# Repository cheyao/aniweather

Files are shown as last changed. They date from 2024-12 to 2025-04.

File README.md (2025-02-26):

<h1 align="center">Aniweather - Your personal anime weather station!</h1>

This is a 3D weather station! You can choose between displaying daily waifu pics and the current weather.

Made for #asylum. The main API code is at https://github.com/cheyao/short with nest :D

PCB image
3D top view
3D bottom view
Case view

To change the settings, edit `firmware/settings.h`! The weather info is mostly parsed on nest.

[ x ] I ran DRC in KiCad and have made sure there are 0 errors!

### BOM 

Provided by dari // alexren:
- 1x WeMos S2 Mini (as a cheaper replacement for the S2) WITHOUT FEMALE HEADERS
- 1x ST7735 1.8" LCD display WITHOUT FEMALE HEADERS. Male headers soldered!

I will be sourcing the following parts with my grant:
- 1x PCB from JLCPCB
    - $2 for 5x + $1.50 shipping
- LCSC:
    - 3x Ceramic THT 1uF capacitor
    - 6x Ceramic THT 0.1uF capacitor
    - 3x Ceramic SMD 0805 10uF capacitor
    - 1x 10ohm THT Resistor
    - 1x 100ohm THT Resistor
    - 1x 470ohm THT Resistor
    - 6x 10kohm THT Resistor
    - 1x TPS2116DRLR
    - 1x TPS63001DRCR

HOME:
- 1x TP4056
- 1x LIPO
- 1x 3D printed case

TOTAL: 15.99+3.5=19.45$

Green LEDs will be brought with the keyboard (min 100 :heavysob:)

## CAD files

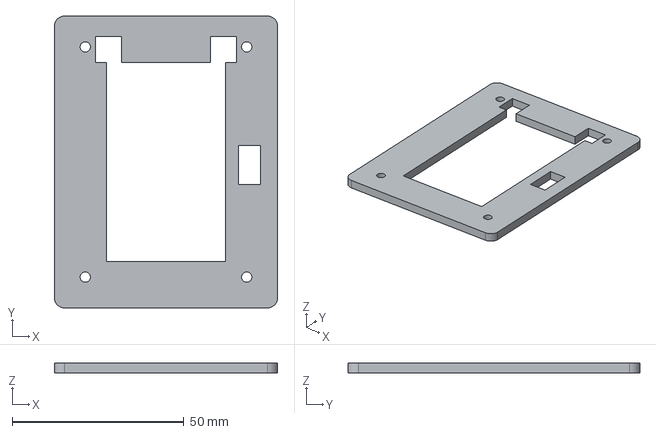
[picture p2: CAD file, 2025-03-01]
CAD/cover.step
65.0 x 85.0 x 3.00 mm

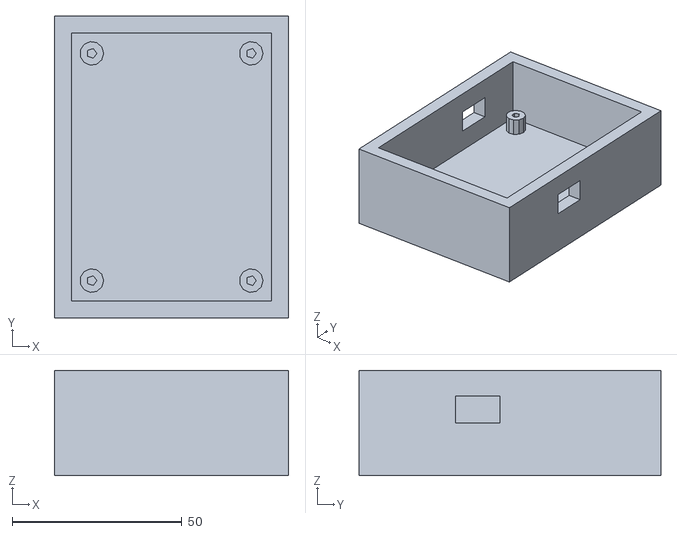
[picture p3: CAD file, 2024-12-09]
CAD/top.stl
69.0 x 89.0 x 31.0

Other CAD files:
CAD/back.scad
CAD/common.scad
CAD/cover.scad
CAD/cover.stl

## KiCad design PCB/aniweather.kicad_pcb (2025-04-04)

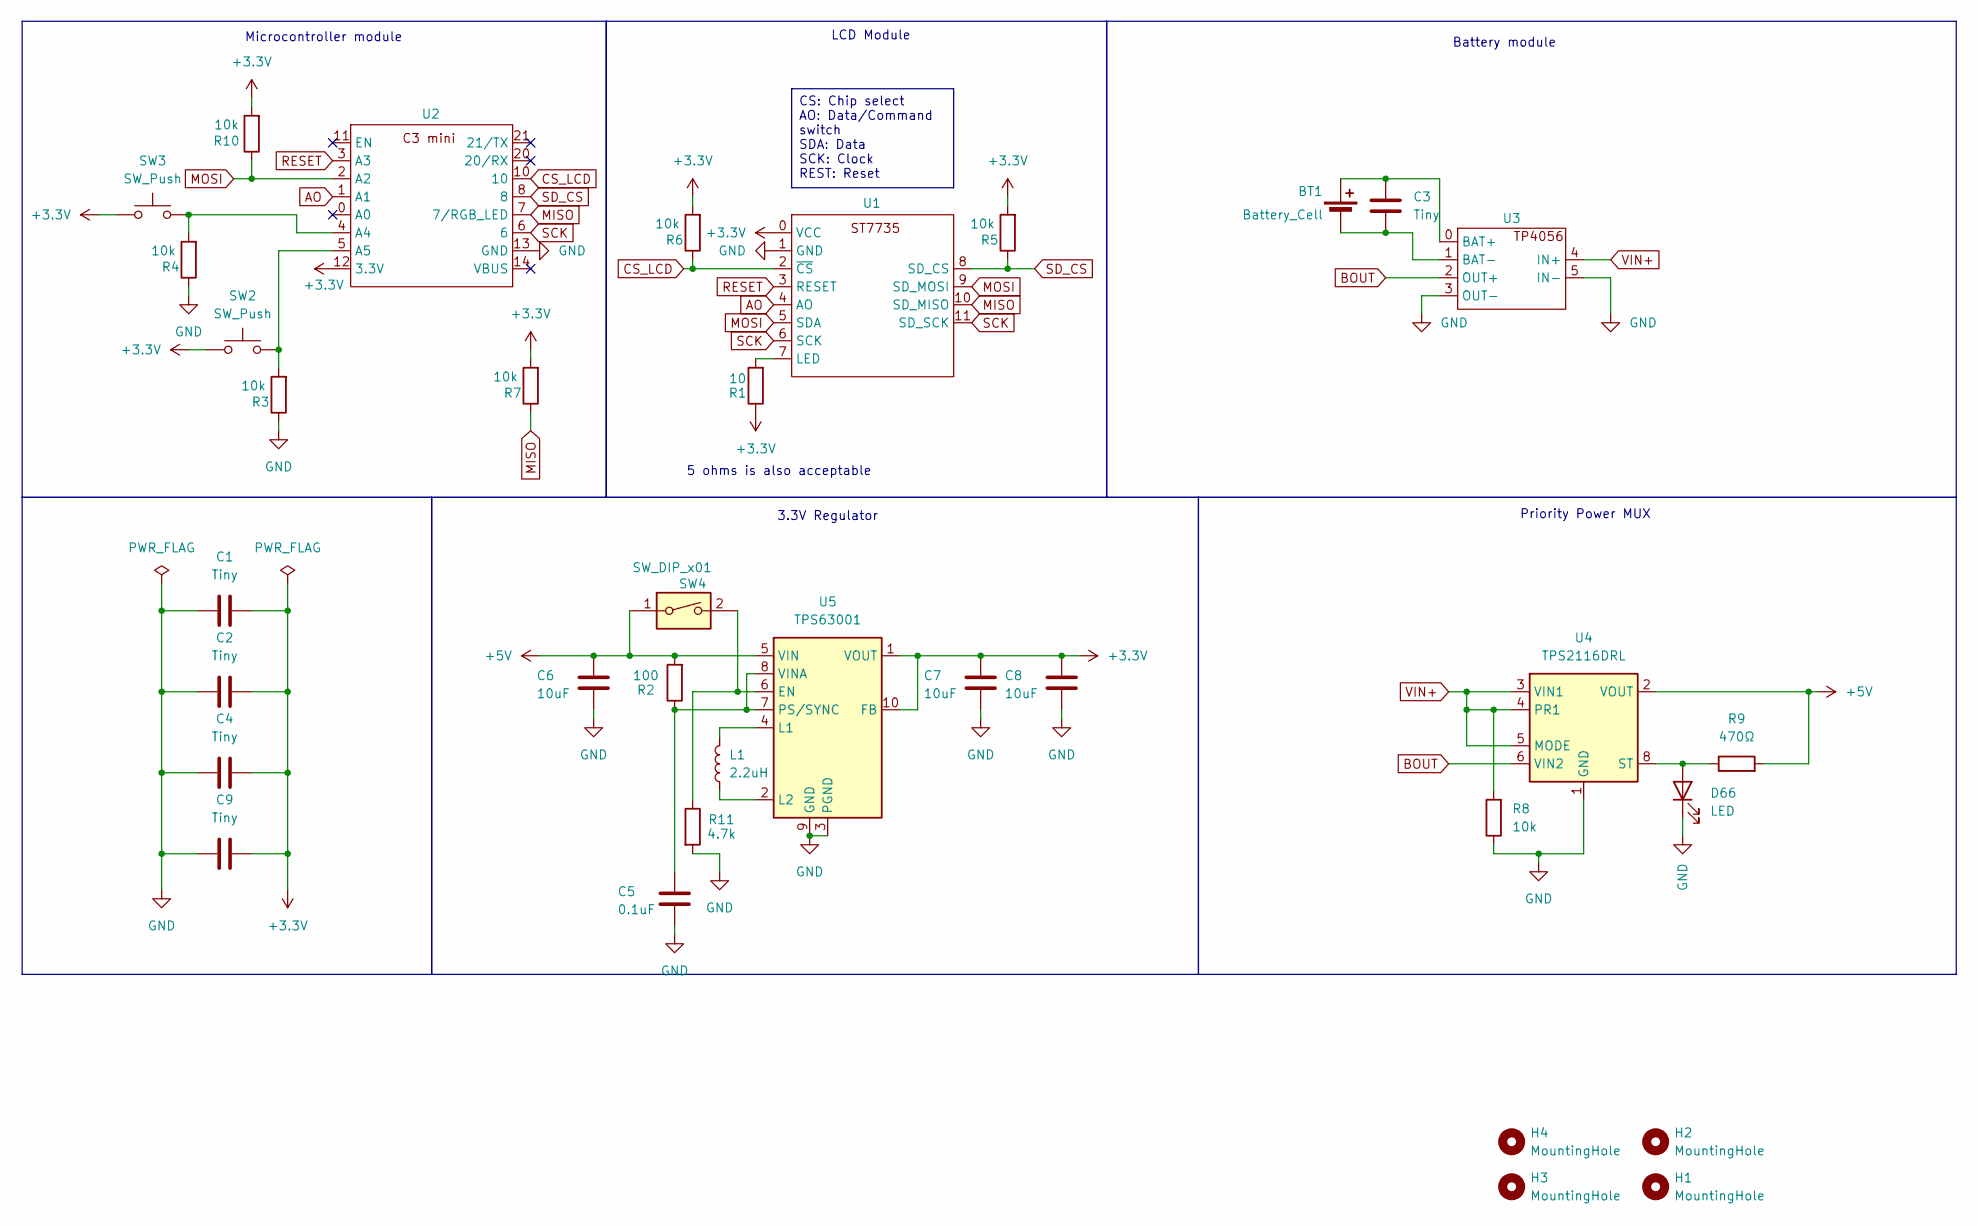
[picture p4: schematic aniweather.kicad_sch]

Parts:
BT1: Battery_Cell; TestPoint_2Pads_Pitch5.08mm_Drill1.3mm
C1, C2, C3, C4, C9: Tiny; C_0805_2012Metric_Pad1.18x1.45mm_HandSolder
C5: 0.1uF; C_0805_2012Metric_Pad1.18x1.45mm_HandSolder
C6, C7, C8: 10uF; C_0805_2012Metric_Pad1.18x1.45mm_HandSolder
D66: LED; LED_0603_1608Metric_Pad1.05x0.95mm_HandSolder
H1, H2, H3, H4: MountingHole; MountingHole_3.2mm_M3
L1: 2.2uH; NR3015T2R2M
R1: 10; R_0805_2012Metric_Pad1.20x1.40mm_HandSolder
R2: 100; R_0805_2012Metric_Pad1.20x1.40mm_HandSolder
R3, R4, R5, R6, R7, R8, R10: 10k; R_0805_2012Metric_Pad1.20x1.40mm_HandSolder
R9: 470Ω; R_0805_2012Metric_Pad1.20x1.40mm_HandSolder
R11: 4.7k; R_0805_2012Metric_Pad1.20x1.40mm_HandSolder
SW2, SW3: SW_Push; SW_PUSH_6mm
SW4: SW_DIP_x01; SW_DIP_SPSTx01_Slide_9.78x4.72mm_W7.62mm_P2.54mm
U1: ST7735
U2: WEMOS_C1_mini
U3: TP4056
U4: TPS2116DRL; SOT-583-8
U5: TPS63001; Texas_DRC0010J_ThermalVias

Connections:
+3.3V: C1.2, C2.2, C4.1, C7.1, C8.1, C9.1, R1.1, R5.2, R6.2, R7.2, R10.2, SW2.1, SW3.1, U1.0 (VCC), U2.12 (3.3V), U5.1 (VOUT), U5.10 (FB)
+5V: C6.1, R2.2, R9.2, SW4.1, U4.2 (VOUT), U4.7 (VOUT), U5.5 (VIN)
AO: U1.4 (AO), U2.1 (A1)
BOUT: U3.2 (OUT+), U4.6 (VIN2)
CS_LCD: R6.1, U1.2 (~CS), U2.10
GND: C1.1, C2.1, C4.2, C5.2, C6.2, C7.2, C8.2, C9.2, D66.1 (K), R3.1, R4.1, R8.1, R11.2, U1.1 (GND), U2.13 (GND), U3.3 (OUT-), U3.5 (IN-), U4.1 (GND), U5.3 (PGND), U5.9 (GND), U5.11 (PGND)
MISO: R7.1, U1.10 (SD_MISO), U2.7 (7/RGB_LED)
MOSI: R10.1, U1.5 (SDA), U1.9 (SD_MOSI), U2.2 (A2)
unnamed: BT1.1 (+), C3.1, U3.0 (BAT+)
unnamed: BT1.2 (-), C3.2, U3.1 (BAT-)
unnamed: D66.2 (A), R9.1, U4.8 (ST)
unnamed: R1.2, U1.7 (LED)
unnamed: R4.2, SW3.2, U2.4 (A4)
unnamed: R3.2, SW2.2, U2.5 (A5)
unnamed: R11.1, SW4.2, U5.6 (EN)
unnamed: L1.2, U5.4 (L1)
unnamed: L1.1, U5.2 (L2)
unnamed: C5.1, R2.1, U5.7 (PS/SYNC), U5.8 (VINA)
RESET: U1.3 (RESET), U2.3 (A3)
SCK: U1.6 (SCK), U1.11 (SD_SCK), U2.6
SD_CS: R5.1, U1.8 (SD_CS), U2.8
VIN+: R8.2, U3.4 (IN+), U4.3 (VIN1), U4.4 (PR1), U4.5 (MODE)

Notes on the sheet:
Microcontroller module
Battery module
3.3V Regulator
Priority Power MUX
5 ohms is also acceptable
LCD Module
CS: Chip select AO: Data/Command switch SDA: Data SCK: Clock REST: Reset

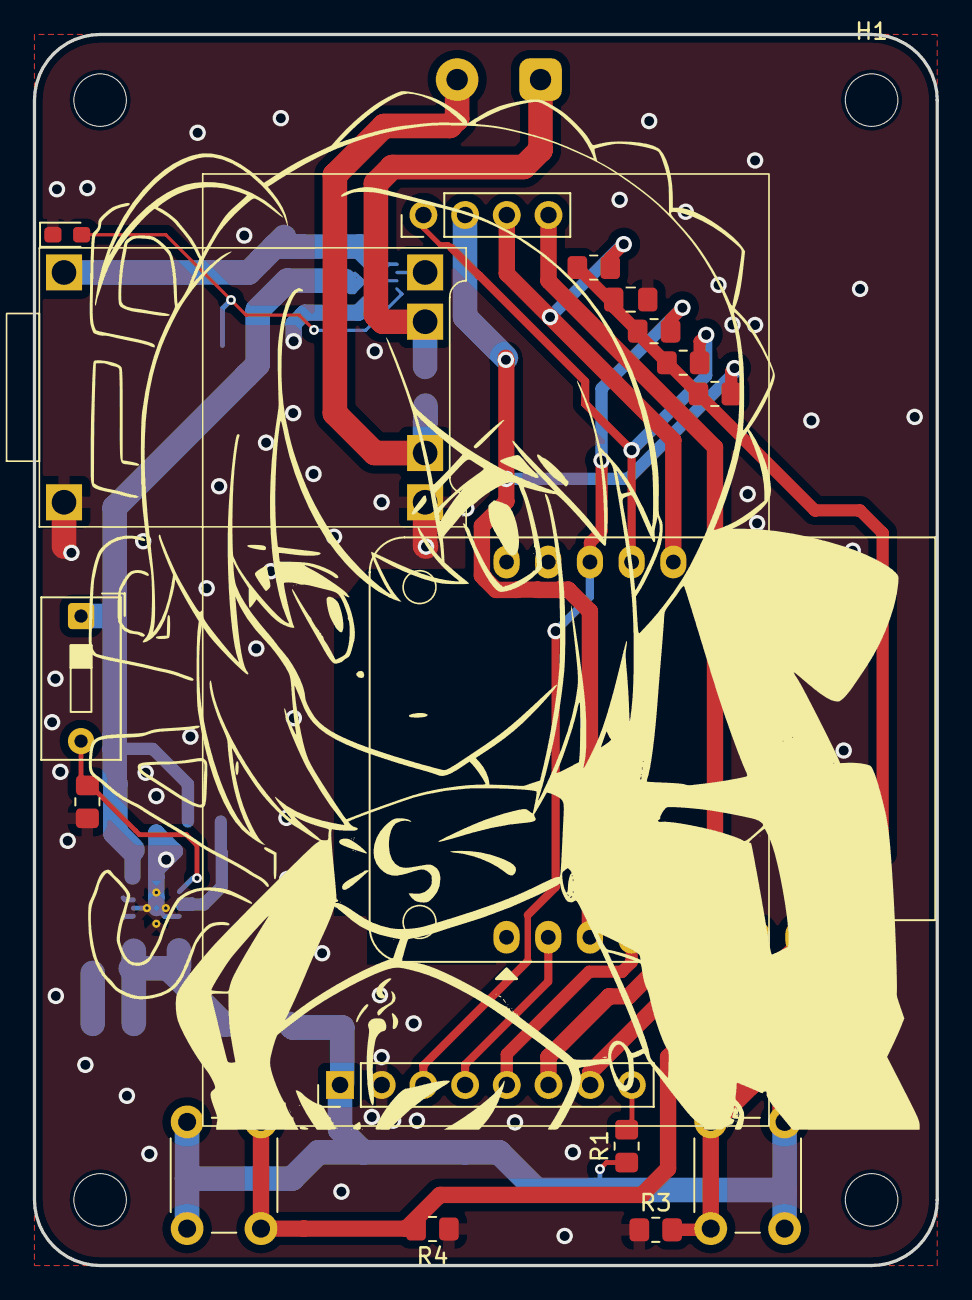
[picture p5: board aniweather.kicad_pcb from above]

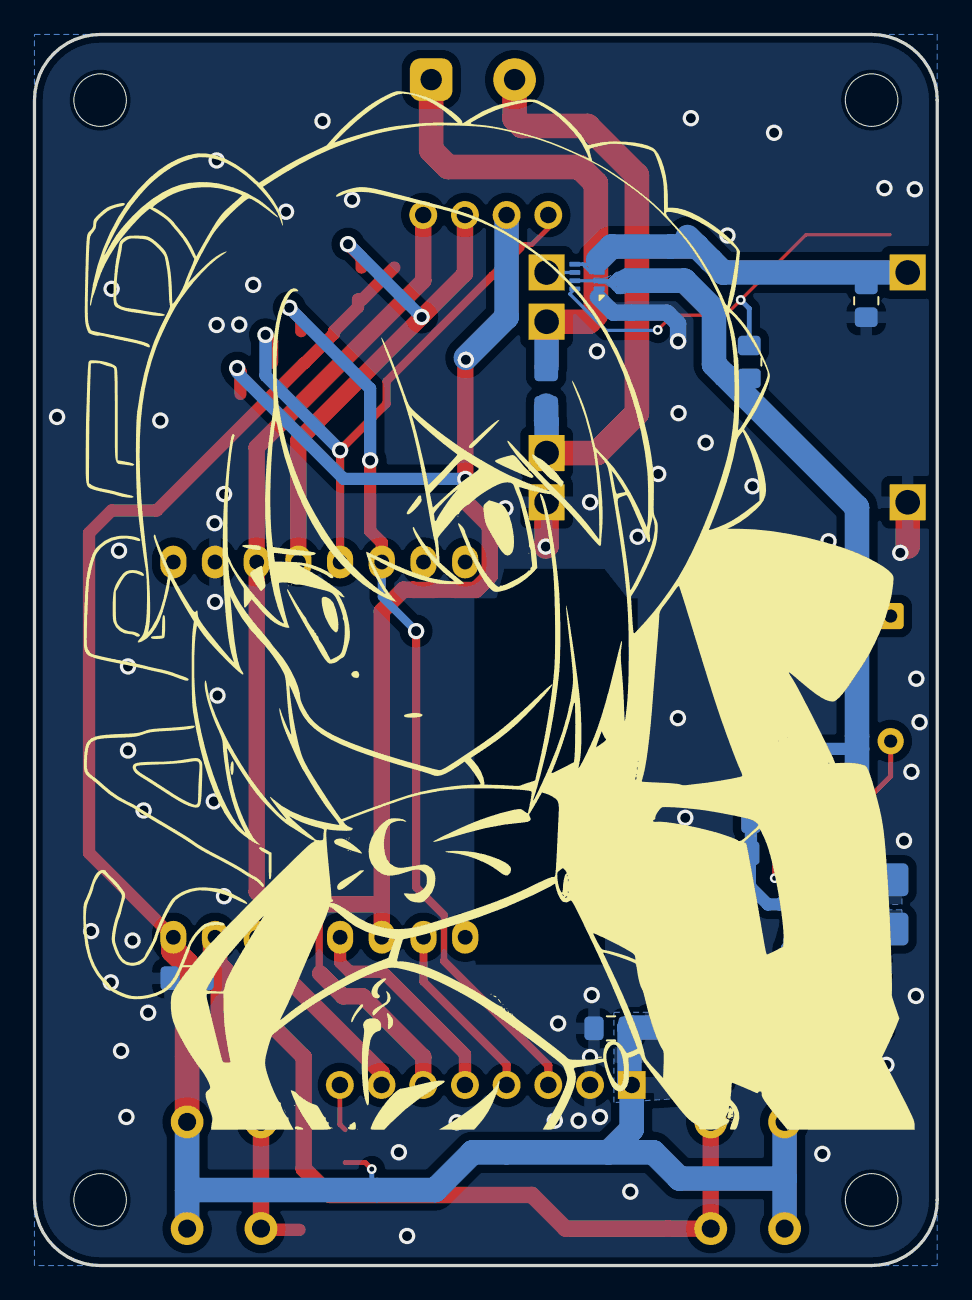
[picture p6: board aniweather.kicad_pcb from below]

Board: 2 copper layers, 55.0 x 75.0 mm, 37 parts (16 on the bottom side), 22 nets.

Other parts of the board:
G1, G2: LOGO

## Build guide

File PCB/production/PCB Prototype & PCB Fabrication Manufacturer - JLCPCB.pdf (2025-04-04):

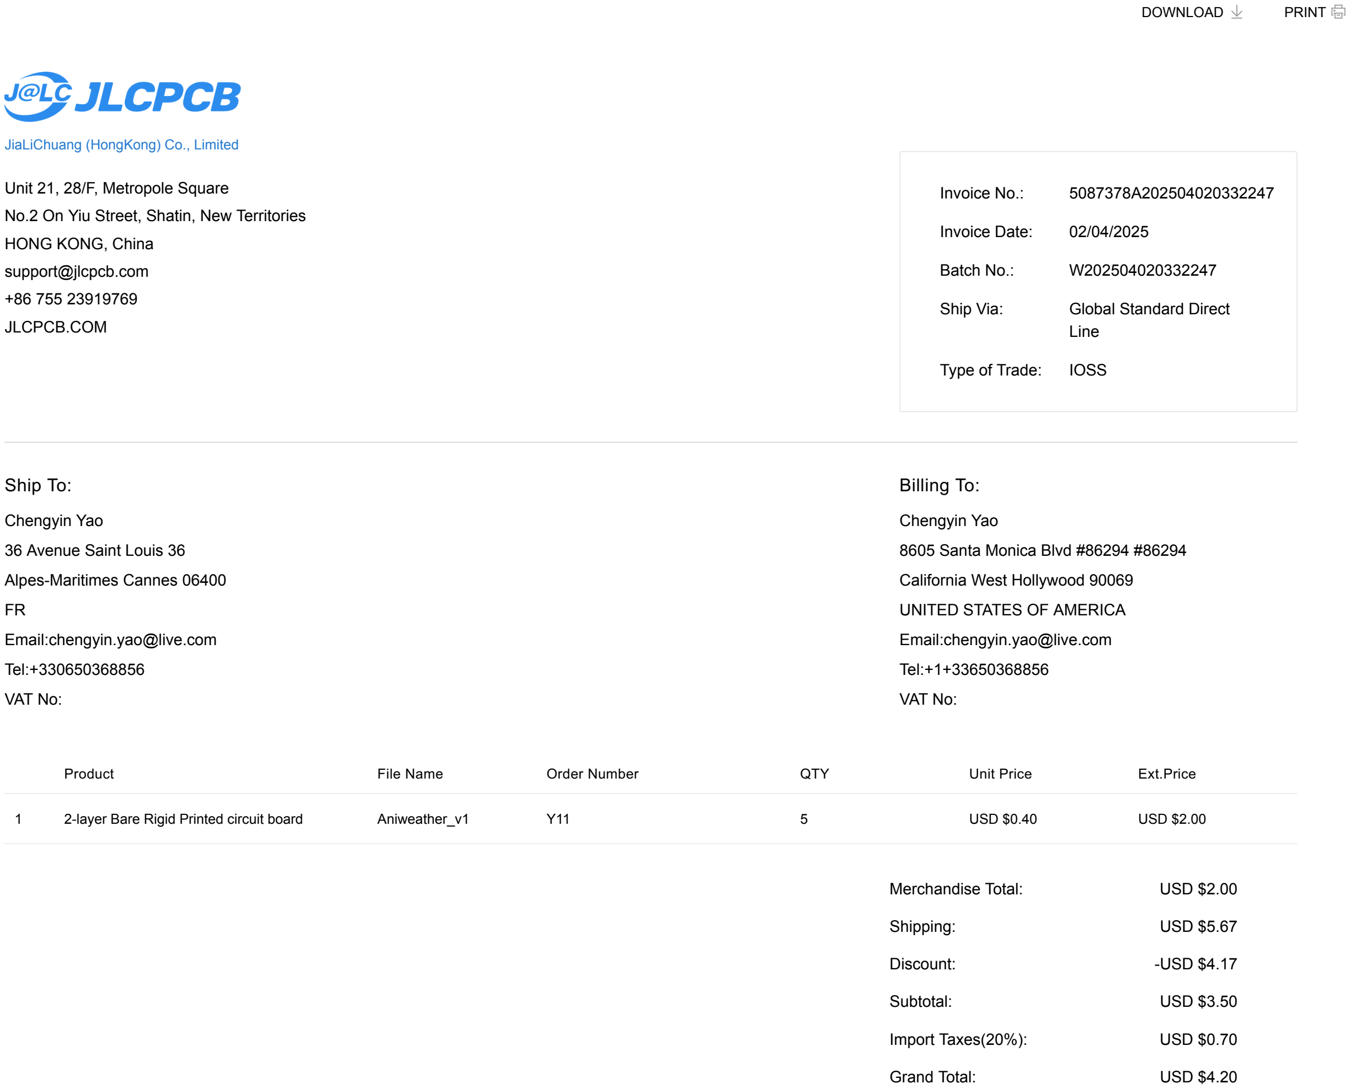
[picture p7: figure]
DOWNLOAD; PRINT; JiaLiChuang (HongKong) Co., Limited; Unit 21, 28/F, Metropole Square; HONG KONG, China; support@jlcpcb.com; JLCPCB.COM; Invoice No.:; Invoice Date:; Batch No.:; Ship Via:; Global Standard Direct; Line; Type of Trade:; IOSS; Ship To:; Chengyin Yao; 36 Avenue Saint Louis 36; Alpes-Maritimes Cannes 06400; Email:chengyin.yao@live.com; Tel:+330650368856; VAT No:; Billing To:; 8605 Santa Monica Blvd #86294 #86294; California West Hollywood 90069; UNITED STATES OF AMERICA; Tel:+1+33650368856; Merchandise Total:; USD $2.00; Shipping:; USD $5.67; Discount:; -USD $4.17; Subtotal: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

No.2 On Yiu Street, Shatin, New Territories

1 | 2-layer Bare Rigid Printed circuit board | Aniweather_v1 | Y11 | 5 | USD $0.40 | USD $2.00
PCB Prototype & PCB Fabrication Manufacturer - JLCPCB | https://jlcpcb.com/user-center/invoice/?batchNum=W20250...
1 of 1 | 4/1/25, 10:19 PM

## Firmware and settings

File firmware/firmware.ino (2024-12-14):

#include <WiFi.h>
#include <SPI.h>

#include "weather.h"

// https://docs.espressif.com/projects/esp-idf/en/stable/esp32c3/api-reference/peripherals/spi_master.html
WeatherStation* station;

void setup() {
	Serial.begin(9600);
	Serial.println("Aniweather booting up...");
	
	station = new WeatherStation();
}

void loop() {
	station->loop();
}

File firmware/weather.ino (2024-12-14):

#include <Adafruit_ST7735.h>
#include <Adafruit_GFX.h>
#include <WiFi.h>
#include <SPI.h>
#include <SD.h>

#include "weather.h"
#include "settings.h"

WeatherStation::WeatherStation() : tft(Adafruit_ST7735(TFT_CS, TFT_DC, TFT_RST)) {
	tft.initR(INITR_BLACKTAB);
	tft.fillScreen(ST77XX_BLACK);
	Serial.println("Screen initialized");

	SD.begin(SD_CS);
	Serial.println("SD card initialized");

	connectWifi();

	// This must be after then WiFi is set up
	Serial.print("Updating time");
	configTime(GMT_OFFSET, DAYLIGHT_OFFSET, NTP_SERVERS);

	// We must wait till the time is correct
	while ((now = time(nullptr)) < NTP_MIN_VALID_EPOCH) {
		Serial.print(".");
		delay(300);
		yield();
	}
	Serial.println("Time configured");

	Serial.printf("Local time: %s", asctime(localtime(&now)));
	Serial.printf("UTC time:   %s", asctime(gmtime(&now)));

	attachInterrupt(digitalPinToInterrupt(RIGHT_BUTTON), rbutton, FALLING);
	attachInterrupt(digitalPinToInterrupt(LEFT_BUTTON), lbutton, FALLING);
	Serial.println("Interrupts initialized");
}

WeatherStation::~WeatherStation() {
	// Cleanup! (Nothing to do lol)
}

void WeatherStation::connectWifi() {
	Serial.println("Connecting to WiFi");
	if (WiFi.status() == WL_CONNECTED) {
		return;
	}

	WiFi.disconnect();
	WiFi.mode(WIFI_MODE_NULL);
	WiFi.hostname(WIFI_HOSTNAME);
	WiFi.mode(WIFI_STA);
	WiFi.begin(WIFI_SSID, WIFI_PASSWORD);
	int progress = 0;
	
	while (WiFi.status() != WL_CONNECTED) {
		delay(500);
	
		if (progress > 80) {
			progress = 0;
		}
		progress += 10;

		// TODO: Draw the progress

		Serial.print(".");
	}

	Serial.println("WiFi connected");
	Serial.printf("IP address: %s/%s\n", WiFi.localIP().toString().c_str(), WiFi.subnetMask().toString().c_str());
	Serial.printf("MAC address: %s\n", WiFi.macAddress().c_str());
}

void WeatherStation::loop() {
	String readRequest = "GET " TEMPERATURE_ENDPOINT " HTTP/1.1\r\n" + "Host: " + METEO_URL + "\r\n"
	+ "Connection: close\r\n\r\n";

	if (!client.connect(METEO_URL, 80)) {
		return;
	}

	client.print(readRequest);
	String response = readResponse();
	testdrawtext(response.c_str(), ST77XX_WHITE);

	sleep(1000 * 60);
}

String WeatherStation::readResponse() {
	unsigned long timeout = millis();
	while (client.available() == 0) {
		if (millis() - timeout > 5000) {
			Serial.println("Client Timeout !");
			client.stop();

			return;
		}
	}

	// Read all the lines of the reply from server and print them to Serial
	String response;
	while (client.available()) {
		response += client.readStringUntil('\r');
	}

	Serial.println(response.c_str());
	Serial.println("Closing connection");
}

void rbutton() {
	rpressed = true;
}

void lbutton() {
	lpressed = true;
}

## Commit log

2024-12-05 Base board
    [aniweather.kicad_pcb, aniweather.kicad_sch]
2024-12-05 Further improvements
    [aniweather.kicad_sch]
2024-12-07 Saber plus PCB start
    [aniweather.kicad_pcb, aniweather.kicad_sch]
2024-12-07 V1.0 rev 1
    [aniweather.kicad_pcb]
2024-12-08 Fix some small issues
    [aniweather.kicad_pcb, aniweather.kicad_sch]
2024-12-08 Bottom case
    [aniweather.kicad_pcb, back.scad, common.scad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]
2024-12-09 Fix USB offset
    [top.scad, top.stl]
2024-12-11 Reroute board
    [aniweather.kicad_pcb, aniweather.kicad_sch]
2024-12-11 Round corner cases and button holes
    [aniweather.kicad_pcb, back.scad, common.scad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]
2024-12-11 Revisions for PCB and start of the firmware
    [aniweather.kicad_pcb, aniweather.kicad_sch]
2024-12-12 Start of WIFI
    [aniweather.kicad_sch]
2024-12-13 Time sync
    [back.scad]
2024-12-14 Final revision
    [aniweather.kicad_pcb, aniweather.kicad_sch, cover.scad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]
2024-12-15 PCB revision
    [aniweather.kicad_pcb, aniweather.kicad_sch]
2024-12-15 I hope this is the final revision
    [aniweather.kicad_pcb, aniweather.kicad_sch]
2024-12-15 Add diode
    [aniweather.kicad_pcb, aniweather.kicad_sch]
2024-12-18 Hope last rev
    [aniweather.kicad_pcb, aniweather.kicad_sch]
2024-12-18 Really last rev
    [aniweather-B_Cu.gbl, aniweather-B_Mask.gbs, aniweather-B_Paste.gbp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]
2024-12-19 Add diode to increase current capacity
    [aniweather.kicad_pcb, aniweather.kicad_sch]
2024-12-24 Readme and last rev
    [aniweather.kicad_pcb, aniweather.kicad_sch]
2024-12-26 Improve case detail
    [back.scad, cover.scad, cover.stl]
2025-01-23 Improve inductor footprint
    [aniweather.kicad_pcb, aniweather.kicad_sch]
2025-02-26 Priority Power MUX
    [aniweather.kicad_pcb, aniweather.kicad_sch, common.scad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]
2025-03-01 FIX MISO and MOSI order
    [aniweather.kicad_pcb, aniweather.kicad_sch, cover.step]
2025-04-01 Use SMD resistors
    [aniweather.kicad_pcb, aniweather.kicad_sch]
